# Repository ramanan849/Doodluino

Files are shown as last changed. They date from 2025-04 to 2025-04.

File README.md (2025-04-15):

# Doodluino: Doodle Jump on Arduino - PH222, Spring '25 Digital Electronics Project

Gokularamanan R S, 23B1854
-
[Project Report](https://github.com/ramanan849/Doodluino/blob/b796de5456497a73b1f6233cb64882a1899941b5/23B1854_Gokularamanan_Doodluino.pdf)
-
- This repo contains the entire version history of my project code, right version 1, till verion 7.4 (the demo day version), the final one. Some of the earlier ones might not be as refined as the latter ones, in terms of both documentation and stability. But, all of them use the same pins for the TFT display, but some versions might have different pins for the joystick. Also, the earlier versions (<= version 4 and or 5) might not have the speaker, LM386 amplifier and musical notes code in them. 
- The log file I tried to maintain : https://docs.google.com/spreadsheets/d/124PygBUTDnI5tR8Jvsb0EWS77CMUWYxi1bj8dvN-BO4/edit?usp=sharing
- [The CAD model files](https://github.com/ramanan849/Doodluino/blob/c0d4e8d1f5cbd4b15ecd3362300d9d8f78787e9c/consoluino%20v3.f3d)
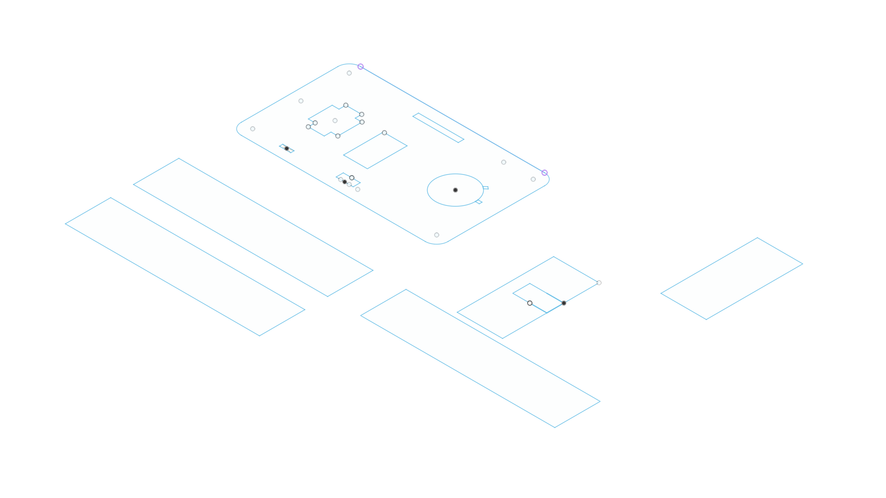
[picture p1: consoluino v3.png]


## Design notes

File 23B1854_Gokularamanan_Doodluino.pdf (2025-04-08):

PH222 | Final Report – 23B1854 | Page 1 of 32
Student: Gokularamanan R S | Roll Number: 23B1854

# Project Title: Doodluino: Doodle Jump on Arduino

# Project Abstract –

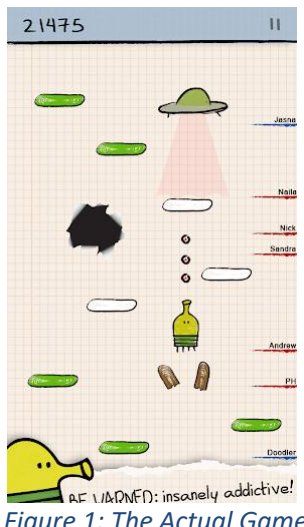
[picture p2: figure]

- Introduction – Doodle Jump is a classic arcade game where players control a small character (the "Doodler") that continuously jumps on randomly spawning, dynamic and stationary platforms, trying to ascend as high as possible without falling. Using a Joystick to move the Doodler left or right, we aim not to fall or get attacked by obstacles like enemies, moving platforms with spikes, and black holes that appear along the way. There are also power-ups, such as

springs and jetpacks that help us jump higher. Ultimately, the goal is to survive and to achieve the highest score.

# - The Grand Goal – TO obtain and simulate the complete version of the game on an Arduino UNO board, respecting all

the game physics and simulations involved.

- Collision detections - SPI update rate - Multi-object dynamics - Interrupts - for performing separate tasks simultaneously, or with minimum delay (in my case, simultaneously playing background music during gameplay through Arduino connected speaker) - EEPROM Memory Allocation - The main inputs and outputs – - Inputs: ■ Joystick – Left and Right Control, Top and Bottom, and Switch - Outputs: ■ TFT Display to display the game ■ Speaker to play game-play music - During the DEMO, I would like to demonstrate my game, by playing each of the Game Levels, showcasing the various features that have been built into it – like

EEPROM utilization, Interrupts, etc.

# - Role of the Arduino – It is the brain of the game. It gets joystick input, outputs the game mechanics to the TFT display and audio via the speaker, powered by the

### Figure 1: The Actual Game

### Credits: Lima Sky (game dev)

LM386 low-power amplifier.

# Project Detail –

# - The major components used –

# 1. Arduino UNO (32 kB storage and 2 kB RAM, with 1 KB allocated for EEPROM) 2. Adafruit ILI9341 2.8’’ TFT SPI Display

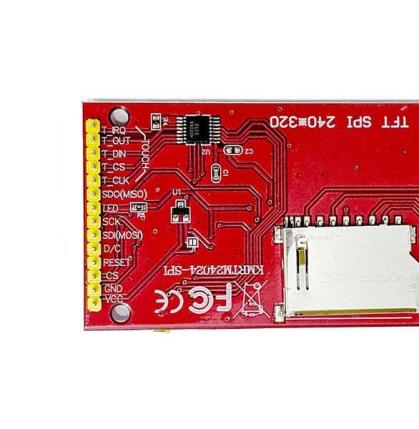
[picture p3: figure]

# 3. Analog Joystick (Left-Right, Top-Bottom, and Select button/ Switch) 4. Speaker (8 Ohm, 0.5 W) 5. LM386, Low Power Amplifier

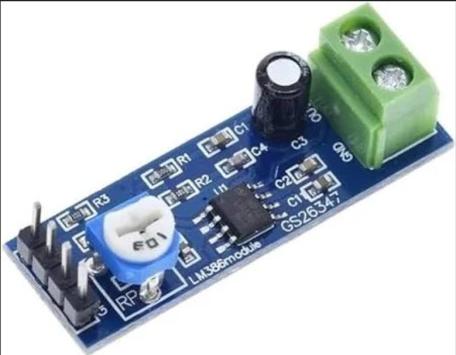
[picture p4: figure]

# 6. Potential Divider Circuit (Used 2.2 Ohm and 3.3 Ohm resistors to precisely deliver 3 V from Arduino 5 V to TFT display, to make sure that it doesn’t get damaged due to heavy load)

## Ref: https://cdn-shop.adafruit.com/datasheets/ILI9341.pdf

# The important pins:

# 1. CS (Chip Select) - Selects ILI9341 for communication 2. DC - Data/Command 3. RST - Reset 4. MOSI - Master Out Slave In 5. SCK – Serial Clock, operates at 16 MHz, same as Uno

# LM386 amplifier –

# 1. operates on a low voltage

2. adjustable gain control,

# using the potentiometer knob

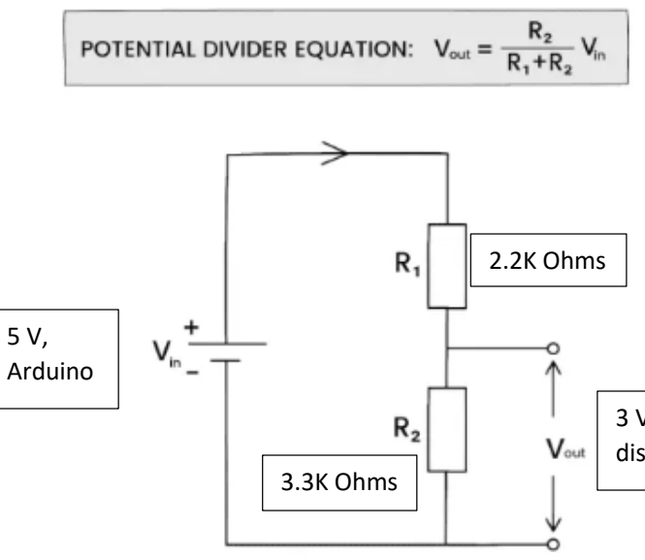
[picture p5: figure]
2.2K Ohms; 3.3K Ohms; Arduino

5 V,

### 3 V to each of the 5 display pins listed above

# - Hardware block diagram –

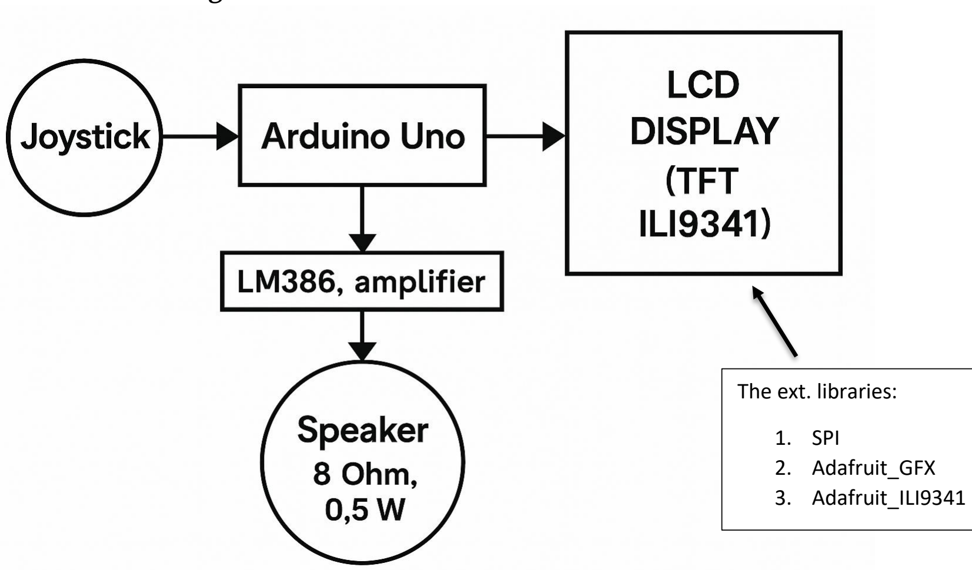
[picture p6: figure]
The ext. libraries:; 1. SPI 2. Adafruit_GFX 3. Adafruit_ILI9341

# - Final Circuit Diagram – (next page)

### Figure 2: Circuit Diagram - Arduino

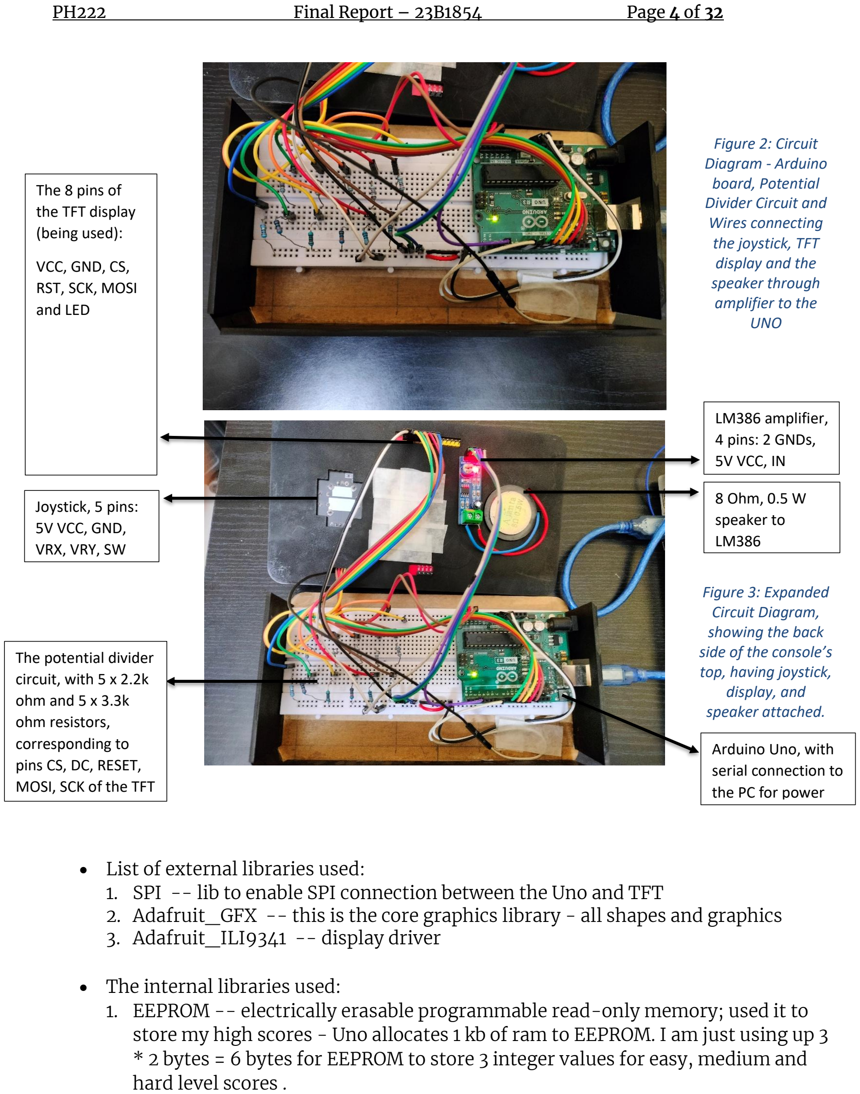
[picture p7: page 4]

# - List of external libraries used: 1. SPI -- lib to enable SPI connection between the Uno and TFT 2. Adafruit_GFX -- this is the core graphics library - all shapes and graphics 3. Adafruit_ILI9341 -- display driver

# - The internal libraries used: 1. EEPROM -- electrically erasable programmable read-only memory; used it to store my high scores - Uno allocates 1 kb of ram to EEPROM. I am just using up 3 * 2 bytes = 6 bytes for EEPROM to store 3 integer values for easy, medium and

hard level scores .

### board, Potential Divider Circuit and Wires connecting the joystick, TFT display and the speaker through amplifier to the UNO

### Figure 3: Expanded

Circuit Diagram,

### showing the back side of the console’s

top, having joystick,

### display, and

speaker attached.

### The 8 pins of the TFT display (being used):

VCC, GND, CS,

### RST, SCK, MOSI and LED

### Joystick, 5 pins:

5V VCC, GND,

### VRX, VRY, SW

### The potential divider circuit, with 5 x 2.2k ohm and 5 x 3.3k

ohm resistors,

### corresponding to

pins CS, DC, RESET,

### MOSI, SCK of the TFT

### Arduino Uno, with serial connection to the PC for power

LM386 amplifier,
4 pins: 2 GNDs,

### 5V VCC, IN

### 8 Ohm, 0.5 W speaker to

LM386

### Joystick

### TFT, displaying the game’s main menu

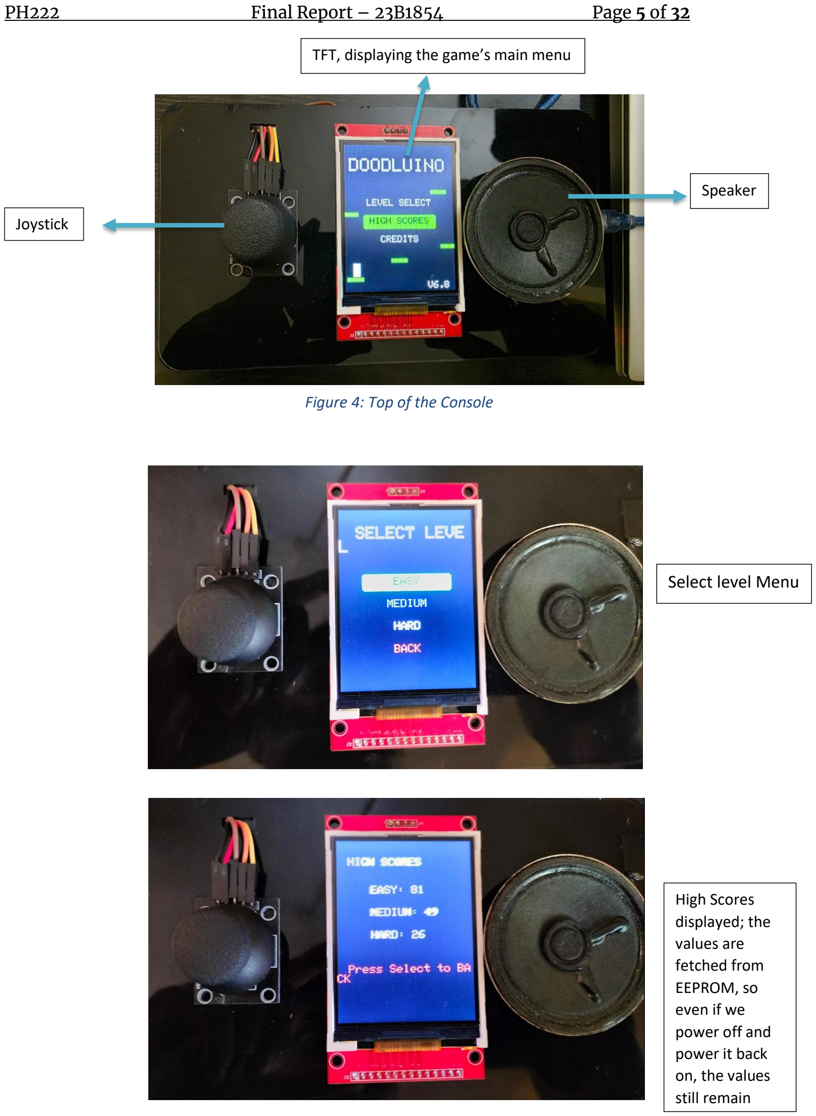
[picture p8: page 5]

### Speaker

### Figure 4: Top of the Console

## Select level Menu

### High Scores displayed; the values are fetched from EEPROM, so even if we power off and power it back on, the values still remain

# - Video Demonstration –

# 1. With Gameplay music

## https://www.youtube.com/watch?v=0u_XmoVJk0Y

# 2. Without gameplay music

## https://www.youtube.com/watch?v=of0zH08SPe8

# Milestones achieved in each week –

1. Note: Since my game involved a lot of components - functions, structures, etc.,

# each of which formed an integral part of my code, I maintained a separate log sheet of my updates every week, what I intended to complete, and the glitches and problems that I faced and needed to rectify along the way:

## https://docs.google.com/spreadsheets/d/124PygBUTDnI5tR8Jvsb0EWS77CMUWYxi1bj8dv

N-BO4/edit?usp=sharing (https://docs.google.com/spreadsheets/d/124PygBUTDnI5tR8Jvsb0EWS77CMUWYxi1bj8dvN-BO4/edit?usp=sharing)

# This turned out to be very useful at the end - I could just check whether I had fixed something or not, since it was very easy to forget very minor, yet hard to fix

glitches.

# 2. Note: I also created a GitHub Repository where I have posted all versions of my

## code, ranging from Version 1.00 to 7.xx: https://github.com/ramanan849/Doodluino

# 3. Overview of my progress throughout the project phase, weekly:

# WEEK 1 – A. Formulated a plan of how I am going to build my project – a basic version of

what kind of features I wanted to build, how I am going to get going with it.

# B. Familiarized myself with the various Arduino components that would be

required.

# C. Explored various Arduino libraries that were capable of displaying animated

objects on a TFT display. Chose to use the TFT library provided by Adafruit. Also, went through others, such as the “TFT-eSPI library” (sadly, incompatible with the UNO due to low clock frequency).

# D. Then, wrote a simple program to animate bouncing balls (my video link:

## https://youtu.be/ppXeX2nozWA)

# WEEK 2 –

# A. Implementing the moving platforms, warp left and right mechanisms, the skeletal features of the game, while optimizing game dynamics to improve animation and FPS

# WEEK 3 –

# A. Designing the in-game graphics - characters and obstacles B. Adding logic to store previous data – EEPROM , such as high scores, and obtaining velocity and position data

# WEEK 4 –

# A. Worked on game GUI B. Tried fixing the SD card and SPI issues

# WEEK 5 –

# A. Fixed Glitches in the game – for Level Easy, Medium and Hard

# B. Worked on using interrupts to play music and play the game simultaneously

# WEEK 6 –

# A. Fixed glitches B. Worked on creating a console from acrylic, used CAD to design the model C. Report

# Code – (As of Tuesday, 08/04/2025, Subject To Change By Demo Day)

// v7.0 - Doodle Jump - As of 08/04/2025
// Gokularamanan RS
// https://github.com/ramanan849/doodluino

/*
List of all the functions in the code, with a one-line explanation :
1. initializeEEPROM()-
2. setup()
3. loop()
4. resetDrawFlags()
5. drawMainMenu()
6. drawLevelMenu()
7. drawHighScores()
8. drawCredits()
9. readMenuInput()
10. handleMenuSelection()
11. readMenuInput_GameOver()
12. updatePlatforms()
13. updateObstacles()
14. drawGame()
15. checkCollisions()
16. initGame()
17. updateMusic()
18. handleGameOver()
19. checkGameOver()
20. handleScrolling()
*/

#include <SPI.h> // lib to enable SPI connection between the Uno and TFT #include <Adafruit_GFX.h> // this is the core graphics library - all shapes and graphics

#include <Adafruit_ILI9341.h> // display driver

#include <EEPROM.h> // EEPROM - electrically erasable programmable read-only memory //- to store my high scores - Uno, i belive allocates 1 kb of ram to eeprom. I am just using up 3 * 2 bytes = 6 bytes for eeprom to store 3 integer values for easy, medium and hard level scores

// --- Pin Definitions ---
// i am using 8 pins on my tft - cs, dc, rst, sck (serial clock), mosi (master out slave in)
#define TFT_CS 10

#define TFT_DC 9

#define TFT_RST 8

#define JOY_X A5

#define JOY_Y A3

#define JOY_SW 6

#define BUZZER_PIN 2

// --- Game Constants ---
#define SCREEN_WIDTH 240

#define SCREEN_HEIGHT 320

// the display is a 240x320 unit #define DOODLER_WIDTH 15
#define DOODLER_HEIGHT 28

#define PLATFORM_WIDTH 40

#define PLATFORM_HEIGHT 8

#define NUM_PLATFORMS 7

#define MAX_SCROLL 5 // Smoother scrolling

#define JUMP_FORCE -12

#define GRAVITY 0.4 // dynamic gravity in updateGame

#define TOP_OFFSET 30 // Height of score panel - the separate one # define BOTTOM_OFFSET 40

#define PLAY_AREA_HEIGHT (SCREEN_HEIGHT - TOP_OFFSET)

#define VISIBLE_PLATFORMS 7 // Start with 7 platforms

#define BASE_SCROLL 5 | // Base scroll speed

#define SCROLL_INCREASE 0.1 // Scroll speed increase per score #define BASE_GRAVITY 0.4 // Base gravity

#define GRAVITY_INCREASE 0.01 // Gravity increase per score #define OBSTACLE_SPEED 2

// <<< NEW: Obstacle Constants >>> #define MAX_OBSTACLES 2
#define OBSTACLE_RADIUS 8

#define OBSTACLE_COLOR RED

#define OBSTACLE_START_SCORE 5

#define OBSTACLE_SPAWN_CHANCE 3 // 3% chance per frame #define OBSTACLE_SPEED 2

#define MIN_OBSTACLE_DISTANCE 40

// --- Game States ---
#define MAIN_MENU 0

#define LEVEL_MENU 1

#define HIGHSCORES_MENU 2

#define CREDITS_MENU 3

#define GAME_PLAYING 4

#define GAME_OVER_STATE 5

// --- Color Definitions ---#define BLACK 0x0000
#define WHITE 0xFFFF

#define GREEN 0x07E0

#define BLUE 0x001F

#define RED 0xF800

#define YELLOW 0xFFE0

#define MAGENTA 0xF81F

#define CYAN 0x07FF

#define LEVEL_EASY 0

#define LEVEL_MEDIUM 1

#define LEVEL_HARD 2

// Musical note definitions
#define NOTE_B0 | 31

#define NOTE_C1 | 33

#define NOTE_CS1 35

#define NOTE_D1 37

#define NOTE_DS1 39

#define NOTE_E1 | 41

#define NOTE_F1 | 44

#define NOTE_FS1 46

#define NOTE_G1 49

#define NOTE_GS1 52

#define NOTE_A1 55

#define NOTE_AS1 58

#define NOTE_B1 62

PH222 | Final Report
– 23B1854 | Page 11 of 32
#define NOTE_C2 | 65

#define NOTE_CS2 69

#define NOTE_D2 73

#define NOTE_DS2 78

#define NOTE_E2 | 82

#define NOTE_F2 | 87

#define NOTE_FS2 93

#define NOTE_G2 98

#define NOTE_GS2 104

#define NOTE_A2 110

#define NOTE_AS2 117

#define NOTE_B2 | 123

#define NOTE_C3 | 131

#define NOTE_CS3 139

#define NOTE_D3 147

#define NOTE_DS3 156

#define NOTE_E3 | 165

#define NOTE_F3 | 175

#define NOTE_FS3 185

#define NOTE_G3 196

#define NOTE_GS3 208

#define NOTE_A3 220

#define NOTE_AS3 233

#define NOTE_B3 | 247

#define NOTE_C4 | 262

#define NOTE_CS4 277

#define NOTE_D4 294

#define NOTE_DS4 311

#define NOTE_E4 | 330

#define NOTE_F4 | 349

#define NOTE_FS4 370

#define NOTE_G4 392

#define NOTE_GS4 415

#define NOTE_A4 440

#define NOTE_AS4 466

#define NOTE_B4 | 494

#define NOTE_C5 | 523

#define NOTE_CS5 554

#define NOTE_D5 587

#define NOTE_DS5 622

#define NOTE_E5 | 659

#define NOTE_F5 | 698

#define NOTE_FS5 740

#define NOTE_G5 784

#define NOTE_GS5 831

#define NOTE_A5 880

#define NOTE_AS5 932

#define NOTE_B5 | 988

#define NOTE_C6 | 1047

#define NOTE_CS6 1109

#define NOTE_D6 1175

#define NOTE_DS6 1245

#define NOTE_E6 | 1319

#define NOTE_F6 | 1397

#define NOTE_FS6 1480

#define NOTE_G6 1568

#define NOTE_GS6 1661

#define NOTE_A6 1760

#define NOTE_AS6 1865

#define NOTE_B6 | 1976

#define NOTE_C7 | 2093

#define NOTE_CS7 2217

#define NOTE_D7 2349

#define NOTE_DS7 2489

#define NOTE_E7 | 2637

#define NOTE_F7 | 2794

#define NOTE_FS7 2960

#define NOTE_G7 3136

#define NOTE_GS7 3322

#define NOTE_A7 3520

#define NOTE_AS7 3729

#define NOTE_B7 | 3951

#define NOTE_C8 | 4186

#define NOTE_CS8 4435

#define NOTE_D8 4699

#define NOTE_DS8 4978

#define REST | 0

enum MusicState { MUSIC_OFF, MUSIC_MAIN, MUSIC_GAME_OVER, MUSIC_CREDITS, MUSIC_HARD }; // basically like a list/ set to store music realted constants

struct GameState { // the most important part of my game - this structure contains most of the variables for spawning platforms, obstacles, making animation and player - arduino interactions possible
int doodlerX, doodlerY;
float doodlerVelocityY;
int platformX[NUM_PLATFORMS];
int platformY[NUM_PLATFORMS];
int platformDirection[NUM_PLATFORMS]; int score = 0;
bool gameOver = true;
bool platformUsed[NUM_PLATFORMS]; int prevDoodlerX, prevDoodlerY; int prevPlatformX[NUM_PLATFORMS];
int prevPlatformY[NUM_PLATFORMS];
int gameLevel = 0;
int selectedOption = 0; // Used by original readMenuInput, now new menu too bool levelSelected = false;
int platformX_start;
int platformY_start;
bool plat_start_used;
bool gameStartedByUser;
int visiblePlatforms;
float displayGravity;
// <<< NEW: Menu state variables >>>
int currentMenu; // Current state (menu, game, etc.) int mainMenuSelection = 0; // For main menu navigation bool gameIsActive = false; // v6.3
// <<< NEW: Obstacle variables >>>
int obstacleX[MAX_OBSTACLES];
int obstacleY[MAX_OBSTACLES];
int obstacleDir[MAX_OBSTACLES]; // 1 = right, -1 = left bool obstacleActive[MAX_OBSTACLES];
int prevObstacleX[MAX_OBSTACLES];
int prevObstacleY[MAX_OBSTACLES];
// the variables corresponding to music MusicState musicState;
int currentMelodyNote;
unsigned long previousNoteTime;
int melodyNoteDuration;
const int* currentMelody;
int currentTempo;
int currentNotesCount;

};

const int melody[] PROGMEM = {
// I took the code from https://github.com/robsoncouto/arduino-songs -- TRUE GOAT // Super Mario Bros theme
// Score available at https://musescore.com/user/2123/scores/2145
// Theme by Koji Kondo
NOTE_E5,8, NOTE_E5,8, REST,8, NOTE_E5,8, REST,8, NOTE_C5,8, NOTE_E5,8, //1 NOTE_G5,4, REST,4, NOTE_G4,8, REST,4,
NOTE_C5,-4, NOTE_G4,8, REST,4, NOTE_E4,-4, // 3
NOTE_A4,4, NOTE_B4,4, NOTE_AS4,8, NOTE_A4,4,
NOTE_G4,-8, NOTE_E5,-8, NOTE_G5,-8, NOTE_A5,4, NOTE_F5,8, NOTE_G5,8, REST,8, NOTE_E5,4,NOTE_C5,8, NOTE_D5,8, NOTE_B4,-4,
NOTE_C5,-4, NOTE_G4,8, REST,4, NOTE_E4,-4, // repeats from 3 NOTE_A4,4, NOTE_B4,4, NOTE_AS4,8, NOTE_A4,4,
NOTE_G4,-8, NOTE_E5,-8, NOTE_G5,-8, NOTE_A5,4, NOTE_F5,8, NOTE_G5,8, REST,8, NOTE_E5,4,NOTE_C5,8, NOTE_D5,8, NOTE_B4,-4,

REST,4, NOTE_G5,8, NOTE_FS5,8, NOTE_F5,8, NOTE_DS5,4, NOTE_E5,8,//7 REST,8, NOTE_GS4,8, NOTE_A4,8, NOTE_C4,8, REST,8, NOTE_A4,8, NOTE_C5,8, NOTE_D5,8,
REST,4, NOTE_DS5,4, REST,8, NOTE_D5,-4,
NOTE_C5,2, REST,2,

REST,4, NOTE_G5,8, NOTE_FS5,8, NOTE_F5,8, NOTE_DS5,4, NOTE_E5,8,//repeats from 7 REST,8, NOTE_GS4,8, NOTE_A4,8, NOTE_C4,8, REST,8, NOTE_A4,8, NOTE_C5,8, NOTE_D5,8,
REST,4, NOTE_DS5,4, REST,8, NOTE_D5,-4,
NOTE_C5,2, REST,2,

NOTE_C5,8, NOTE_C5,4, NOTE_C5,8, REST,8, NOTE_C5,8, NOTE_D5,4,//11 NOTE_E5,8, NOTE_C5,4, NOTE_A4,8, NOTE_G4,2,

NOTE_C5,8, NOTE_C5,4, NOTE_C5,8, REST,8, NOTE_C5,8, NOTE_D5,8, NOTE_E5,8,//13 REST,1,
NOTE_C5,8, NOTE_C5,4, NOTE_C5,8, REST,8, NOTE_C5,8, NOTE_D5,4,
NOTE_E5,8, NOTE_C5,4, NOTE_A4,8, NOTE_G4,2,
NOTE_E5,8, NOTE_E5,8, REST,8, NOTE_E5,8, REST,8, NOTE_C5,8, NOTE_E5,4, NOTE_G5,4, REST,4, NOTE_G4,4, REST,4,
NOTE_C5,-4, NOTE_G4,8, REST,4, NOTE_E4,-4, // 19

NOTE_A4,4, NOTE_B4,4, NOTE_AS4,8, NOTE_A4,4,
NOTE_G4,-8, NOTE_E5,-8, NOTE_G5,-8, NOTE_A5,4, NOTE_F5,8, NOTE_G5,8, REST,8, NOTE_E5,4, NOTE_C5,8, NOTE_D5,8, NOTE_B4,-4,

NOTE_C5,-4, NOTE_G4,8, REST,4, NOTE_E4,-4, // repeats from 19 NOTE_A4,4, NOTE_B4,4, NOTE_AS4,8, NOTE_A4,4,
NOTE_G4,-8, NOTE_E5,-8, NOTE_G5,-8, NOTE_A5,4, NOTE_F5,8, NOTE_G5,8, REST,8, NOTE_E5,4, NOTE_C5,8, NOTE_D5,8, NOTE_B4,-4,

NOTE_E5,8, NOTE_C5,4, NOTE_G4,8, REST,4, NOTE_GS4,4,//23
NOTE_A4,8, NOTE_F5,4, NOTE_F5,8, NOTE_A4,2,
NOTE_D5,-8, NOTE_A5,-8, NOTE_A5,-8, NOTE_A5,-8, NOTE_G5,-8, NOTE_F5,-8,

NOTE_E5,8, NOTE_C5,4, NOTE_A4,8, NOTE_G4,2, //26
NOTE_E5,8, NOTE_C5,4, NOTE_G4,8, REST,4, NOTE_GS4,4,
NOTE_A4,8, NOTE_F5,4, NOTE_F5,8, NOTE_A4,2,
NOTE_B4,8, NOTE_F5,4, NOTE_F5,8, NOTE_F5,-8, NOTE_E5,-8, NOTE_D5,-8, NOTE_C5,8, NOTE_E4,4, NOTE_E4,8, NOTE_C4,2,

NOTE_E5,8, NOTE_C5,4, NOTE_G4,8, REST,4, NOTE_GS4,4,//repeats from 23

NOTE_A4,8, NOTE_F5,4, NOTE_F5,8, NOTE_A4,2,
NOTE_D5,-8, NOTE_A5,-8, NOTE_A5,-8, NOTE_A5,-8, NOTE_G5,-8, NOTE_F5,-8,

NOTE_E5,8, NOTE_C5,4, NOTE_A4,8, NOTE_G4,2, //26
NOTE_E5,8, NOTE_C5,4, NOTE_G4,8, REST,4, NOTE_GS4,4,
NOTE_A4,8, NOTE_F5,4, NOTE_F5,8, NOTE_A4,2,
NOTE_B4,8, NOTE_F5,4, NOTE_F5,8, NOTE_F5,-8, NOTE_E5,-8, NOTE_D5,-8, NOTE_C5,8, NOTE_E4,4, NOTE_E4,8, NOTE_C4,2,
NOTE_C5,8, NOTE_C5,4, NOTE_C5,8, REST,8, NOTE_C5,8, NOTE_D5,8, NOTE_E5,8, REST,1,

NOTE_C5,8, NOTE_C5,4, NOTE_C5,8, REST,8, NOTE_C5,8, NOTE_D5,4, //33 NOTE_E5,8, NOTE_C5,4, NOTE_A4,8, NOTE_G4,2,
NOTE_E5,8, NOTE_E5,8, REST,8, NOTE_E5,8, REST,8, NOTE_C5,8, NOTE_E5,4, NOTE_G5,4, REST,4, NOTE_G4,4, REST,4,
NOTE_E5,8, NOTE_C5,4, NOTE_G4,8, REST,4, NOTE_GS4,4,
NOTE_A4,8, NOTE_F5,4, NOTE_F5,8, NOTE_A4,2,
NOTE_D5,-8, NOTE_A5,-8, NOTE_A5,-8, NOTE_A5,-8, NOTE_G5,-8, NOTE_F5,-8,

NOTE_E5,8, NOTE_C5,4, NOTE_A4,8, NOTE_G4,2, //40
NOTE_E5,8, NOTE_C5,4, NOTE_G4,8, REST,4, NOTE_GS4,4,
NOTE_A4,8, NOTE_F5,4, NOTE_F5,8, NOTE_A4,2,
NOTE_B4,8, NOTE_F5,4, NOTE_F5,8, NOTE_F5,-8, NOTE_E5,-8, NOTE_D5,-8, NOTE_C5,8, NOTE_E4,4, NOTE_E4,8, NOTE_C4,2,
};

const int gameOver[] PROGMEM = {
// Super Mario's gameOver
// I took the code from https://github.com/robsoncouto/arduino-songs -- TRUE GOAT NOTE_C5,-4, NOTE_G4,-4, NOTE_E4,4, //45
NOTE_A4,-8, NOTE_B4,-8, NOTE_A4,-8, NOTE_GS4,-8, NOTE_AS4,-8, NOTE_GS4,-8, NOTE_G4,8, NOTE_D4,8, NOTE_E4,-2,
};

const int hardMelody[] PROGMEM = {
// credits: Beethoven
// I took the code from https://github.com/robsoncouto/arduino-songs -- TRUE GOAT NOTE_E5, 16, NOTE_DS5, 16, //1
NOTE_E5, 16, NOTE_DS5, 16, NOTE_E5, 16, NOTE_B4, 16, NOTE_D5, 16, NOTE_C5, 16, NOTE_A4, -8, NOTE_C4, 16, NOTE_E4, 16, NOTE_A4, 16,
NOTE_B4, -8, NOTE_E4, 16, NOTE_GS4, 16, NOTE_B4, 16,
NOTE_C5, 8, | REST, 16, NOTE_E4, 16, NOTE_E5, 16, | NOTE_DS5, 16,

NOTE_E5, 16, NOTE_DS5, 16, NOTE_E5, 16, NOTE_B4, 16, NOTE_D5, 16, NOTE_C5, 16,//6 NOTE_A4, -8, NOTE_C4, 16, NOTE_E4, 16, NOTE_A4, 16,
NOTE_B4, -8, NOTE_E4, 16, NOTE_C5, 16, NOTE_B4, 16,
NOTE_A4 , 4, REST, 8, //9 - 1st ending

//repaets from 1 ending on 10
NOTE_E5, 16, NOTE_DS5, 16, //1
NOTE_E5, 16, NOTE_DS5, 16, NOTE_E5, 16, NOTE_B4, 16, NOTE_D5, 16, NOTE_C5, 16, NOTE_A4, -8, NOTE_C4, 16, NOTE_E4, 16, NOTE_A4, 16,
NOTE_B4, -8, NOTE_E4, 16, NOTE_GS4, 16, NOTE_B4, 16,
NOTE_C5, 8, | REST, 16, NOTE_E4, 16, NOTE_E5, 16, | NOTE_DS5, 16,

NOTE_E5, 16, NOTE_DS5, 16, NOTE_E5, 16, NOTE_B4, 16, NOTE_D5, 16, NOTE_C5, 16,//6 NOTE_A4, -8, NOTE_C4, 16, NOTE_E4, 16, NOTE_A4, 16,
NOTE_B4, -8, NOTE_E4, 16, NOTE_C5, 16, NOTE_B4, 16,
NOTE_A4, 8, REST, 16, NOTE_B4, 16, NOTE_C5, 16, NOTE_D5, 16, //10 - 2nd ending //continues from 11
NOTE_E5, -8, NOTE_G4, 16, NOTE_F5, 16, NOTE_E5, 16,
NOTE_D5, -8, NOTE_F4, 16, NOTE_E5, 16, NOTE_D5, 16, //12

NOTE_C5, -8, NOTE_E4, 16, NOTE_D5, 16, NOTE_C5, 16, //13
NOTE_B4, 8, REST, 16, NOTE_E4, 16, NOTE_E5, 16, REST, 16,
REST, 16, NOTE_E5, 16, NOTE_E6, 16, REST, 16, REST, 16, NOTE_DS5, 16, NOTE_E5, 16, REST, 16, REST, 16, NOTE_DS5, 16, NOTE_E5, 16, NOTE_DS5, 16, NOTE_E5, 16, NOTE_DS5, 16, NOTE_E5, 16, NOTE_B4, 16, NOTE_D5, 16, NOTE_C5, 16, NOTE_A4, 8, REST, 16, NOTE_C4, 16, NOTE_E4, 16, NOTE_A4, 16,

NOTE_B4, 8, REST, 16, NOTE_E4, 16, NOTE_GS4, 16, NOTE_B4, 16, //19
NOTE_C5, 8, REST, 16, NOTE_E4, 16, NOTE_E5, 16, NOTE_DS5, 16,
NOTE_E5, 16, NOTE_DS5, 16, NOTE_E5, 16, NOTE_B4, 16, NOTE_D5, 16, NOTE_C5, 16, NOTE_A4, 8, REST, 16, NOTE_C4, 16, NOTE_E4, 16, NOTE_A4, 16,
NOTE_B4, 8, REST, 16, NOTE_E4, 16, NOTE_C5, 16, NOTE_B4, 16,
NOTE_A4, 8, REST, 16, NOTE_B4, 16, NOTE_C5, 16, NOTE_D5, 16, //24 (1st ending)

//repeats from 11
NOTE_E5, -8, NOTE_G4, 16, NOTE_F5, 16, NOTE_E5, 16,
NOTE_D5, -8, NOTE_F4, 16, NOTE_E5, 16, NOTE_D5, 16, //12

NOTE_C5, -8, NOTE_E4, 16, NOTE_D5, 16, NOTE_C5, 16, //13
NOTE_B4, 8, REST, 16, NOTE_E4, 16, NOTE_E5, 16, REST, 16,
REST, 16, NOTE_E5, 16, NOTE_E6, 16, REST, 16, REST, 16, NOTE_DS5, 16, NOTE_E5, 16, REST, 16, REST, 16, NOTE_DS5, 16, NOTE_E5, 16, NOTE_DS5, 16, NOTE_E5, 16, NOTE_DS5, 16, NOTE_E5, 16, NOTE_B4, 16, NOTE_D5, 16, NOTE_C5, 16, NOTE_A4, 8, REST, 16, NOTE_C4, 16, NOTE_E4, 16, NOTE_A4, 16,

NOTE_B4, 8, REST, 16, NOTE_E4, 16, NOTE_GS4, 16, NOTE_B4, 16, //19
NOTE_C5, 8, REST, 16, NOTE_E4, 16, NOTE_E5, 16, NOTE_DS5, 16,
NOTE_E5, 16, NOTE_DS5, 16, NOTE_E5, 16, NOTE_B4, 16, NOTE_D5, 16, NOTE_C5, 16, NOTE_A4, 8, REST, 16, NOTE_C4, 16, NOTE_E4, 16, NOTE_A4, 16,
NOTE_B4, 8, REST, 16, NOTE_E4, 16, NOTE_C5, 16, NOTE_B4, 16,
NOTE_A4, 8, REST, 16, NOTE_C5, 16, NOTE_C5, 16, NOTE_C5, 16, //25 - 2nd ending

//continues from 26
NOTE_C5 , 4, NOTE_F5, -16, NOTE_E5, 32, //26
NOTE_E5, 8, NOTE_D5, 8, NOTE_AS5, -16, NOTE_A5, 32,
NOTE_A5, 16, NOTE_G5, 16, NOTE_F5, 16, NOTE_E5, 16, NOTE_D5, 16, NOTE_C5, 16, NOTE_AS4, 8, NOTE_A4, 8, NOTE_A4, 32, NOTE_G4, 32, NOTE_A4, 32, NOTE_B4, 32, NOTE_C5 , 4, NOTE_D5, 16, NOTE_DS5, 16,
NOTE_E5, -8, NOTE_E5, 16, NOTE_F5, 16, NOTE_A4, 16,
NOTE_C5 , 4, NOTE_D5, -16, NOTE_B4, 32,

NOTE_C5, 32, NOTE_G5, 32, NOTE_G4, 32, NOTE_G5, 32, NOTE_A4, 32, NOTE_G5, 32, NOTE_B4, 32, NOTE_G5, 32, NOTE_C5, 32, NOTE_G5, 32, NOTE_D5, 32, NOTE_G5, 32, //33 NOTE_E5, 32, NOTE_G5, 32, NOTE_C6, 32, NOTE_B5, 32, NOTE_A5, 32, NOTE_G5, 32, NOTE_F5, 32, NOTE_E5, 32, NOTE_D5, 32, NOTE_G5, 32, NOTE_F5, 32, NOTE_D5, 32, NOTE_C5, 32, NOTE_G5, 32, NOTE_G4, 32, NOTE_G5, 32, NOTE_A4, 32, NOTE_G5, 32, NOTE_B4, 32, NOTE_G5, 32, NOTE_C5, 32, NOTE_G5, 32, NOTE_D5, 32, NOTE_G5, 32,

NOTE_E5, 32, NOTE_G5, 32, NOTE_C6, 32, NOTE_B5, 32, NOTE_A5, 32, NOTE_G5, 32, NOTE_F5, 32, NOTE_E5, 32, NOTE_D5, 32, NOTE_G5, 32, NOTE_F5, 32, NOTE_D5, 32, //36 NOTE_E5, 32, NOTE_F5, 32, NOTE_E5, 32, NOTE_DS5, 32, NOTE_E5, 32, NOTE_B4, 32, NOTE_E5, 32, NOTE_DS5, 32, NOTE_E5, 32, NOTE_B4, 32, NOTE_E5, 32, NOTE_DS5, 32, NOTE_E5, -8, NOTE_B4, 16, NOTE_E5, 16, NOTE_DS5, 16,
NOTE_E5, -8, NOTE_B4, 16, NOTE_E5, 16, REST, 16,

REST, 16, NOTE_DS5, 16, NOTE_E5, 16, REST, 16, REST, 16, NOTE_DS5, 16, //40 NOTE_E5, 16, NOTE_DS5, 16, NOTE_E5, 16, NOTE_B4, 16, NOTE_D5, 16, NOTE_C5, 16, NOTE_A4, 8, REST, 16, NOTE_C4, 16, NOTE_E4, 16, NOTE_A4, 16,
NOTE_B4, 8, REST, 16, NOTE_E4, 16, NOTE_GS4, 16, NOTE_B4, 16,
NOTE_C5, 8, REST, 16, NOTE_E4, 16, NOTE_E5, 16, NOTE_DS5, 16,

NOTE_E5, 16, NOTE_DS5, 16, NOTE_E5, 16, NOTE_B4, 16, NOTE_D5, 16, NOTE_C5, 16,

NOTE_A4, 8, REST, 16, NOTE_C4, 16, NOTE_E4, 16, NOTE_A4, 16, //46
NOTE_B4, 8, REST, 16, NOTE_E4, 16, NOTE_C5, 16, NOTE_B4, 16,
NOTE_A4, 8, REST, 16, NOTE_B4, 16, NOTE_C5, 16, NOTE_D5, 16, NOTE_E5, -8, NOTE_G4, 16, NOTE_F5, 16, NOTE_E5, 16,
NOTE_D5, -8, NOTE_F4, 16, NOTE_E5, 16, NOTE_D5, 16,
NOTE_C5, -8, NOTE_E4, 16, NOTE_D5, 16, NOTE_C5, 16,
NOTE_B4, 8, REST, 16, NOTE_E4, 16, NOTE_E5, 16, REST, 16,
REST, 16, NOTE_E5, 16, NOTE_E6, 16, REST, 16, REST, 16, NOTE_DS5, 16,

NOTE_E5, 16, REST, 16, REST, 16, NOTE_DS5, 16, NOTE_E5, 16, NOTE_D5, 16, //54 NOTE_E5, 16, NOTE_DS5, 16, NOTE_E5, 16, NOTE_B4, 16, NOTE_D5, 16, NOTE_C5, 16, NOTE_A4, 8, REST, 16, NOTE_C4, 16, NOTE_E4, 16, NOTE_A4, 16,
NOTE_B4, 8, REST, 16, NOTE_E4, 16, NOTE_GS4, 16, NOTE_B4, 16,
NOTE_C5, 8, REST, 16, NOTE_E4, 16, NOTE_E5, 16, NOTE_DS5, 16,
NOTE_E5, 16, NOTE_DS5, 16, NOTE_E5, 16, NOTE_B4, 16, NOTE_D5, 16, NOTE_C5, 16,

NOTE_A4, 8, REST, 16, NOTE_C4, 16, NOTE_E4, 16, NOTE_A4, 16, //60
NOTE_B4, 8, REST, 16, NOTE_E4, 16, NOTE_C5, 16, NOTE_B4, 16,
NOTE_A4, 8, REST, 16, REST, 16, REST, 8,
NOTE_CS5 , -4,
NOTE_D5 , 4, NOTE_E5, 16, NOTE_F5, 16,
NOTE_F5 , 4, NOTE_F5, 8,
NOTE_E5 , -4,
NOTE_D5 , 4, NOTE_C5, 16, NOTE_B4, 16, NOTE_A4 , 4, NOTE_A4, 8,
NOTE_A4, 8, NOTE_C5, 8, NOTE_B4, 8, NOTE_A4 , -4,
NOTE_CS5 , -4,

NOTE_D5 , 4, NOTE_E5, 16, NOTE_F5, 16, //72 NOTE_F5 , 4, NOTE_F5, 8,
NOTE_F5 , -4,
NOTE_DS5 , 4, NOTE_D5, 16, NOTE_C5, 16, NOTE_AS4 , 4, NOTE_A4, 8,
NOTE_GS4 , 4, NOTE_G4, 8,
NOTE_A4 , -4,
NOTE_B4 , 4, REST, 8,
NOTE_A3, -32, NOTE_C4, -32, NOTE_E4, -32, NOTE_A4, -32, NOTE_C5, -32, NOTE_E5, -32, NOTE_D5, -32, NOTE_C5, -32, NOTE_B4, -32,

NOTE_A4, -32, NOTE_C5, -32, NOTE_E5, -32, NOTE_A5, -32, NOTE_C6, -32, NOTE_E6, -32, NOTE_D6, -32, NOTE_C6, -32, NOTE_B5, -32, //80
NOTE_A4, -32, NOTE_C5, -32, NOTE_E5, -32, NOTE_A5, -32, NOTE_C6, -32, NOTE_E6, -32, NOTE_D6, -32, NOTE_C6, -32, NOTE_B5, -32,
NOTE_AS5, -32, NOTE_A5, -32, NOTE_GS5, -32, NOTE_G5, -32, NOTE_FS5, -32, NOTE_F5, -32, NOTE_E5, -32, NOTE_DS5, -32, NOTE_D5, -32,

NOTE_CS5, -32, NOTE_C5, -32, NOTE_B4, -32, NOTE_AS4, -32, NOTE_A4, -32, NOTE_GS4, -32, NOTE_G4, -32, NOTE_FS4, -32, NOTE_F4, -32, //84
NOTE_E4, 16, NOTE_DS5, 16, NOTE_E5, 16, NOTE_B4, 16, NOTE_D5, 16, NOTE_C5, 16, NOTE_A4, -8, NOTE_C4, 16, NOTE_E4, 16, NOTE_A4, 16,
NOTE_B4, -8, NOTE_E4, 16, NOTE_GS4, 16, NOTE_B4, 16,

NOTE_C5, 8, REST, 16, NOTE_E4, 16, NOTE_E5, 16, NOTE_DS5, 16, //88
NOTE_E5, 16, NOTE_DS5, 16, NOTE_E5, 16, NOTE_B4, 16, NOTE_D5, 16, NOTE_C5, 16, NOTE_A4, -8, NOTE_C4, 16, NOTE_E4, 16, NOTE_A4, 16,
NOTE_B4, -8, NOTE_E4, 16, NOTE_C5, 16, NOTE_B4, 16,
NOTE_A4, -8, REST, -8,
REST, -8, NOTE_G4, 16, NOTE_F5, 16, NOTE_E5, 16, NOTE_D5 , 4, REST, 8,

REST, -8, NOTE_E4, 16, NOTE_D5, 16, NOTE_C5, 16,

NOTE_B4, -8, NOTE_E4, 16, NOTE_E5, 8, //96
NOTE_E5, 8, NOTE_E6, -8, NOTE_DS5, 16,
NOTE_E5, 16, REST, 16, REST, 16, NOTE_DS5, 16, NOTE_E5, 16, NOTE_DS5, 16, NOTE_E5, 16, NOTE_DS5, 16, NOTE_E5, 16, NOTE_B4, 16, NOTE_D5, 16, NOTE_C5, 16, NOTE_A4, -8, NOTE_C4, 16, NOTE_E4, 16, NOTE_A4, 16,
NOTE_B4, -8, NOTE_E4, 16, NOTE_GS4, 16, NOTE_B4, 16,

NOTE_C5, 8, REST, 16, NOTE_E4, 16, NOTE_E5, 16, NOTE_DS5, 16, //102
NOTE_E5, 16, NOTE_DS5, 16, NOTE_E5, 16, NOTE_B4, 16, NOTE_D5, 16, NOTE_C5, 16, NOTE_A4, -8, NOTE_C4, 16, NOTE_E4, 16, NOTE_A4, 16,
NOTE_B4, -8, NOTE_E4, 16, NOTE_C5, 16, NOTE_B4, 16,
NOTE_A4 , -4,
};

const int creditMelody[] PROGMEM = {
// credits : Never Gonna Give You Up, Rick AStley
// I took the code from https://github.com/robsoncouto/arduino-songs -- TRUE GOAT REST,8, NOTE_B4,8, NOTE_B4,8, NOTE_CS5,8, NOTE_D5,8, NOTE_B4,4, NOTE_A4,8, //7 NOTE_A5,8, REST,8, NOTE_A5,8, NOTE_E5,-4, REST,4,
NOTE_B4,8, NOTE_B4,8, NOTE_CS5,8, NOTE_D5,8, NOTE_B4,8, NOTE_D5,8, NOTE_E5,8, REST,8,
REST,8, NOTE_CS5,8, NOTE_B4,8, NOTE_A4,-4, REST,4,
REST,8, NOTE_B4,8, NOTE_B4,8, NOTE_CS5,8, NOTE_D5,8, NOTE_B4,8, NOTE_A4,4, NOTE_E5,8, NOTE_E5,8, NOTE_E5,8, NOTE_FS5,8, NOTE_E5,4, REST,4,

};

int hard_tempo = 80;
int tempo = 200; // for both mario and game over int credit_tempo = 114;

int wholenote_mario = (60000 * 4) / tempo;
int wholenote_hard = (60000 * 4) / hard_tempo;
int wholenote_credit = (60000 * 4) / credit_tempo;
int wholenote_gameover = (60000 * 4) / tempo;
int notes = sizeof(melody) / sizeof(melody[0]) / 2; // for mario int notes_hard = sizeof(hardMelody) / sizeof(hardMelody[0]) / 2; int notes_gameover = sizeof(gameOver) / sizeof(gameOver[0]) / 2; int notes_credit = sizeof(creditMelody) / sizeof(hardMelody[0]) / 2;

const int easyAddress = 0;
const int medAddress = 2; // Assuming sizeof(int) == 2 on target const int highAddress = 4;
const int INIT_MARKER_ADDR = 6;
const float HOMING_FACTOR = 0.8;

// --- Global Variables () ---
bool beat_easy = 0; // Used in original handleGameOver - ref v5 bool beat_med = 0; // Used in original handleGameOver - ref v5
bool beat_hard = 0; // Used in original handleGameOver - ref v5

Adafruit_ILI9341 tft(TFT_CS, TFT_DC, TFT_RST); // this declr initalizes the tft display -
//basically, the white startup and a then flashdown animation that happens at the start is due to this

// --- Moving Platform Constants () ---
const int PLATFORM_MOVE_SPEED = 1;
const int PLATFORM_MOVE_RANGE = 50; // movement range

// <<< NEW: Flags for menu drawing state >>>
static bool mainMenuFirstDraw = true;
static bool levelMenuFirstDraw = true; static bool highScoresDrawn = false; static bool creditsDrawn = false; static bool gameOverMsgDrawn = false;

// === EEPROM Function (Original ) ===
void initializeEEPROM() {
//Serial.println("Initializing EEPROM check...");
if (EEPROM.read(INIT_MARKER_ADDR) != 0x33) { // Check new marker address //Serial.println("Initializing EEPROM with default high score values"); EEPROM.put(easyAddress, highScore.easy_score);
EEPROM.put(medAddress, highScore.med_score);
EEPROM.put(highAddress, highScore.hard_score); EEPROM.write(INIT_MARKER_ADDR, 0x33); // Write marker to new address } else {
//Serial.println("EEPROM already initialized."); EEPROM.get(easyAddress, highScore.easy_score);
//Serial.print("Easy Level High Score = "); Serial.println(highScore.easy_score);
EEPROM.get(medAddress, highScore.med_score);
//Serial.print("Med Level High Score = "); Serial.println(highScore.med_score); EEPROM.get(highAddress, highScore.hard_score);
//Serial.print("Hard Level High Score = "); Serial.println(highScore.hard_score);
}
}

// === Setup Function (MODIFIED for State Machine) ===
void setup() {
//Serial.begin(115200);
//Serial.println("v5 Base Code + New Menu Setup..."); // Identify version

// Hardware Init ()
pinMode(TFT_RST, OUTPUT);
pinMode(JOY_SW, INPUT_PULLUP);
digitalWrite(TFT_RST, LOW); delay(10); digitalWrite(TFT_RST, HIGH); delay(10);

tft.begin();
tft.setRotation(0);
SPI.setClockDivider(SPI_CLOCK_DIV2); // Keep as per code

// EEPROM Init ()
initializeEEPROM();
// EEPROM gets (redundant if initializeEEPROM does it, but keep if intended) EEPROM.get(easyAddress, highScore.easy_score);
EEPROM.get(medAddress, highScore.med_score);
EEPROM.get(highAddress, highScore.hard_score);

// <<< NEW: Initialize state machine >>> state.currentMenu = MAIN_MENU; // Start at main menu state.mainMenuSelection = 0;

state.gameOver = true; // Ensure game isn't running initially state.levelSelected = false; // Reset flag

randomSeed(analogRead(A0)); // Seed random generator (use a floating pin like A0) }

// === Main Loop (REPLACED with State Machine) ===
void loop() {
updateMusic();
switch (state.currentMenu) {
case MAIN_MENU:
drawMainMenu();
readMenuInput(); // New non-blocking input handler break;
case LEVEL_MENU:
drawLevelMenu(); // New non-blocking draw handler readMenuInput(); // New non-blocking input handler break;
case HIGHSCORES_MENU:
drawHighScores();
readMenuInput();
break;
case CREDITS_MENU:
drawCredits();
readMenuInput();
break;
case GAME_PLAYING:
// Use original game loop structure if (!state.gameOver) {
// Original throttle logic
static uint32_t lastUpdate = 0;
if (millis() - lastUpdate < 33) return; // Original throttle lastUpdate = millis();

updateGame(); // Calls ORIGINAL updateGame
drawGame(); // Calls ORIGINAL drawGame
} else {
// If gameOver becomes true, transition state
// updateHighScore logic moved into handleGameOver state.currentMenu = GAME_OVER_STATE; resetDrawFlags();
}
break;
case GAME_OVER_STATE:
handleGameOver(); | // Display score, update EEPROM (Adapted from
original)
readMenuInput_GameOver(); // Wait for input to return to menu
break;
}
}

// === NEW Menu Drawing Functions ===
void resetDrawFlags() {
mainMenuFirstDraw = true; levelMenuFirstDraw = true;
highScoresDrawn = false; creditsDrawn = false; gameOverMsgDrawn = false; }

void drawMainMenu() {
static int lastSelection = -1;
if (state.mainMenuSelection != lastSelection || mainMenuFirstDraw) { if (mainMenuFirstDraw) {

tft.fillScreen(BLACK); tft.setTextColor(WHITE); tft.setTextSize(4); tft.setCursor(10, 30); tft.print("DOODLUINO"); tft.setTextSize(2); mainMenuFirstDraw = false;
} else { tft.fillRect(35, 110, 170, 130, BLACK); }

const char* menuItems[] = {"LEVEL SELECT", "HIGH SCORES", "CREDITS"}; for (int i = 0; i < 3; i++) {
int yPos = 120 + (i * 40);
uint16_t fgColor = WHITE, bgColor = GREEN;
if (i == state.mainMenuSelection) { tft.fillRoundRect(40, yPos - 5, 160, 30, 5, bgColor); fgColor = BLACK; }
tft.setTextColor(fgColor);
int textWidth = strlen(menuItems[i]) * 6 * 2;
tft.setCursor(SCREEN_WIDTH / 2 - textWidth / 2, yPos); tft.print(menuItems[i]);
}
lastSelection = state.mainMenuSelection;
}
tft.fillRect(-3,150,PLATFORM_WIDTH-8, PLATFORM_HEIGHT, GREEN); tft.fillRect(190,100,PLATFORM_WIDTH-5, PLATFORM_HEIGHT, GREEN); tft.fillRect(100,250,PLATFORM_WIDTH-5, PLATFORM_HEIGHT, GREEN); // dont - oh no!!!
tft.fillRect(4,290,PLATFORM_WIDTH-5, PLATFORM_HEIGHT, GREEN); tft.fillRect(150,340,PLATFORM_WIDTH-5, PLATFORM_HEIGHT, GREEN); tft.fillRect(210,220,PLATFORM_WIDTH-5, PLATFORM_HEIGHT, GREEN); tft.fillRect(17, 260 ,DOODLER_WIDTH, DOODLER_HEIGHT, WHITE);

tft.setCursor(180,300);
tft.print("V7.0");
}

void drawLevelMenu() {
static int lastSelection = -1;
const int numOptions = 4; // Easy, Med, Hard, Back
if (state.selectedOption != lastSelection || levelMenuFirstDraw) {
if (levelMenuFirstDraw) {
tft.fillScreen(BLACK); tft.setTextColor(WHITE); tft.setTextSize(3); tft.setCursor(30, 30); tft.print("SELECT LEVEL"); tft.setTextSize(2); levelMenuFirstDraw = false;
} else { tft.fillRect(35, 110, 170, 170, BLACK); } // Clear menu area + back

for (int i = 0; i < numOptions; i++) { // Loop includes Back option
int yPos = 120 + (i * 40);
bool isSelected = (i == state.selectedOption);
uint16_t color = BLUE; // Default highlight for Back
uint16_t textColor = WHITE;
const char* optionText = "";

if (isSelected) {
if (i == LEVEL_EASY) color = GREEN; else if (i == LEVEL_MEDIUM) color = YELLOW; else if (i == LEVEL_HARD) color = RED; tft.fillRoundRect(40, yPos - 5, 160, 30, 5, color);
}

switch (i) {
case LEVEL_EASY: optionText = "EASY"; textColor = (isSelected ? BLACK : WHITE); break;
case LEVEL_MEDIUM: optionText = "MEDIUM"; textColor = (isSelected ? BLACK : BLUE); break;

case LEVEL_HARD: optionText = "HARD"; textColor = (isSelected ? BLACK : WHITE); break;
case 3: optionText = "BACK"; textColor = (isSelected ? WHITE : RED); break; }
tft.setTextColor(textColor);
int textWidth = strlen(optionText) * 6 * 2;
tft.setCursor(SCREEN_WIDTH / 2 - textWidth / 2, yPos); tft.print(optionText); }
lastSelection = state.selectedOption;
}
}

void drawHighScores() {
if (!highScoresDrawn) {
tft.fillScreen(BLACK); tft.setTextColor(WHITE); tft.setTextSize(2); tft.setCursor(20, 30); tft.print("HIGH SCORES");
tft.setCursor(60, 80); tft.print("EASY: "); tft.print(highScore.easy_score); tft.setCursor(60, 120); tft.print("MEDIUM: "); tft.print(highScore.med_score);
tft.setCursor(60, 160); tft.print("HARD: "); tft.print(highScore.hard_score); tft.setTextColor(RED); tft.setCursor(20, 220); tft.print("Press Select to BACK");
highScoresDrawn = true;
}
}

void drawCredits() {
if (!creditsDrawn) {
tft.fillScreen(BLACK); tft.setTextColor(WHITE); tft.setTextSize(3); tft.setCursor(60, 50); tft.print("CREDITS"); tft.setTextSize(2); tft.setCursor(30, 120); tft.print("Game By: LUKOG"); // name

tft.setTextColor(RED); tft.setCursor(20, 220); tft.print("Press Select to BACK");
creditsDrawn = true;
}
}

// === NEW Input Handling Functions ===
void readMenuInput() {
static uint32_t lastInputTime = 0; uint32_t now = millis(); if (now -lastInputTime < 180) return;
int yValue = analogRead(JOY_Y); int swValue = digitalRead(JOY_SW); bool inputProcessed = false; int currentSelection = 0; int maxOption = 0;

switch(state.currentMenu) {
case MAIN_MENU: currentSelection = state.mainMenuSelection; maxOption = 2; break;
case LEVEL_MENU: currentSelection = state.selectedOption; maxOption = 3; break;
case HIGHSCORES_MENU: case CREDITS_MENU: break; default: return;
}
if (state.currentMenu == MAIN_MENU || state.currentMenu == LEVEL_MENU) {
// Use thresholds consistent with original readMenuInput if different
if (yValue > 600) { currentSelection++; if (currentSelection > maxOption) currentSelection = 0; inputProcessed = true; }
else if (yValue < 400) { currentSelection--; if (currentSelection < 0) currentSelection = maxOption; inputProcessed = true; }
if (inputProcessed) { if(state.currentMenu == MAIN_MENU) state.mainMenuSelection = currentSelection; else if (state.currentMenu == LEVEL_MENU) state.selectedOption = currentSelection; lastInputTime = now; } }

if (swValue == LOW) { handleMenuSelection(); lastInputTime = now + 250; } // Debounce after select
}

void handleMenuSelection() {
int previousMenu = state.currentMenu; switch(state.currentMenu) {
case MAIN_MENU:
switch(state.mainMenuSelection) {
case 0: state.currentMenu = LEVEL_MENU; state.selectedOption = 0; break;
case 1: state.currentMenu = HIGHSCORES_MENU; break;
case 2: state.currentMenu = CREDITS_MENU;
state.currentMenu = CREDITS_MENU; state.musicState = MUSIC_CREDITS; state.currentMelody = creditMelody; state.currentTempo = credit_tempo; state.currentNotesCount =
sizeof(creditMelody)/sizeof(creditMelody[0])/2; state.currentMelodyNote = 0; break;
} break;
case LEVEL_MENU:
if (state.selectedOption == 3) { state.currentMenu = MAIN_MENU; state.mainMenuSelection = 0; }
else { state.gameLevel = state.selectedOption; state.levelSelected = true; state.currentMenu = GAME_PLAYING; tft.fillScreen(RED); delay(2);
tft.fillScreen(YELLOW);
delay(2);
tft.fillScreen(GREEN);
delay(2);
tft.fillScreen(BLACK);initGame(); } // Calls ORIGINAL initGame break;
case HIGHSCORES_MENU: case CREDITS_MENU: state.currentMenu = MAIN_MENU; state.musicState = MUSIC_OFF; noTone(BUZZER_PIN); state.mainMenuSelection = (previousMenu == HIGHSCORES_MENU) ? 1 : 2; break;
}
if (state.currentMenu != previousMenu) { resetDrawFlags(); }
}

void readMenuInput_GameOver() {
static uint32_t lastInputTime_GO = 0; uint32_t now = millis(); if (now -lastInputTime_GO < 400) return;
if (digitalRead(JOY_SW) == LOW) { state.currentMenu = MAIN_MENU; state.mainMenuSelection = 0; state.gameOver = true; lastInputTime_GO = now; resetDrawFlags(); }
}

void updateGame() { // Modify existing updateGame

// Store previous positions first state.prevDoodlerX = state.doodlerX; state.prevDoodlerY = state.doodlerY;

// <<< NEW: Check if the game is active >>> if (!state.gameIsActive) {
// --- PRE-GAME IDLE STATE ---

// 1. Check for Start Trigger (Joystick Button Press)

if (digitalRead(JOY_SW) == LOW) {
state.gameIsActive = true; // Start the game! state.doodlerVelocityY = JUMP_FORCE; // Apply initial full jump force // Serial.println("Game Started!"); // Debug message

return; // Skip rest of update for this frame
}

// 2. Idle Bounce Physics (simple bounce on platform 0)
const float IDLE_GRAVITY = 0.1f; // Very weak gravity for idle const float IDLE_JUMP = -1.5f; // Small upward bounce velocity

state.doodlerVelocityY += IDLE_GRAVITY; // Apply weak gravity state.doodlerY += state.doodlerVelocityY; // Update position

// Collision check ONLY with platform 0 (the starting one)
int i = 0; // Index of the starting platform
bool xOverlap = (state.doodlerX + DOODLER_WIDTH > state.platformX[i]) && (state.doodlerX < state.platformX[i] + PLATFORM_WIDTH); // Simplified Y check for idle bounce (are feet at or below platform top?) bool yLanded = (state.doodlerY + DOODLER_HEIGHT >= state.platformY[i]);

// Apply bounce only if falling and landed
if (xOverlap && yLanded && state.doodlerVelocityY >= 0) { state.doodlerVelocityY = IDLE_JUMP; // Apply small bounce state.doodlerY = state.platformY[i] - DOODLER_HEIGHT; // Snap to top }

// Make sure regular platforms update their prev positions but don't move // Call original updatePlatforms but it should ideally do nothing if level==easy
// or if platformDirection is 0 for the relevant platforms
updatePlatforms(); // Keep original call - needed to update prevX/Y for drawing

} else {
// --- ACTIVE GAME STATE

// Input handling (Horizontal)
int joy = analogRead(JOY_X);
// Use the horizontal control logic from v5 code:
state.doodlerX += (joy < 400) ? +5 : (joy > 600) ? -5 : 0; // Assuming this is v5 logic
// Screen wrap
if (state.doodlerX < 0) state.doodlerX = SCREEN_WIDTH - DOODLER_WIDTH;
if (state.doodlerX > SCREEN_WIDTH - DOODLER_WIDTH) state.doodlerX = 0;

// Physics (Normal Gravity - using original dynamic gravity)
float dynamicGravity = BASE_GRAVITY + (state.score * GRAVITY_INCREASE); state.displayGravity = dynamicGravity;
state.doodlerVelocityY += dynamicGravity;
// Apply terminal velocity (optional)
// state.doodlerVelocityY = min(state.doodlerVelocityY, 15.0f); state.doodlerY += state.doodlerVelocityY;

// Standard Game Logic Calls ( Original Functions) updateObstacles();
checkCollisions();
handleScrolling();
updatePlatforms(); // Platforms will move now based on level/direction checkGameOver();
}

}

void updatePlatforms() {
int moveSpeed = PLATFORM_MOVE_SPEED;

// Adjust speed based on level and score if (state.gameLevel == LEVEL_HARD) { moveSpeed += state.score * 0.25;
}

for (int i = 0; i < NUM_PLATFORMS; i++) {
if (state.gameLevel != LEVEL_EASY) {
state.platformX[i] += moveSpeed * state.platformDirection[i]; // Boundary check
if (state.platformX[i] <= 0) {
state.platformDirection[i] = 1;
state.platformX[i] = 0;
} else if (state.platformX[i] >= SCREEN_WIDTH - PLATFORM_WIDTH) { state.platformDirection[i] = -1;
state.platformX[i] = SCREEN_WIDTH - PLATFORM_WIDTH;
}
}
}
}

void updateObstacles() {
// Calculate current max obstacles based on score (1 + 1 per 10 points) int currentMaxObstacles = 1 + (state.score / 10);
currentMaxObstacles = min(currentMaxObstacles, MAX_OBSTACLES);

// Spawn new obstacles
if (state.score >= OBSTACLE_START_SCORE && random(100) < OBSTACLE_SPAWN_CHANCE) { for (int i = 0; i < currentMaxObstacles; i++) { // Only check allowed slots if (!state.obstacleActive[i]) {
state.obstacleActive[i] = true;
state.obstacleX[i] = random(OBSTACLE_RADIUS, SCREEN_WIDTH -OBSTACLE_RADIUS);

// Homing effect only in Hard mode
if (state.gameLevel == LEVEL_HARD) {
float horizontalDifference = state.doodlerX - state.obstacleX[i]; if (horizontalDifference > 5) {
state.obstacleX[i] += HOMING_FACTOR;
}
else if (horizontalDifference < -5) { state.obstacleX[i] -= HOMING_FACTOR;
}
// Keep within bounds after adjustment state.obstacleX[i] = constrain(state.obstacleX[i], OBSTACLE_RADIUS,
SCREEN_WIDTH - OBSTACLE_RADIUS);
}

state.obstacleY[i] = random(-PLATFORM_HEIGHT+20, 0); state.obstacleDir[i] = (random(2) ? 1 : -1); state.prevObstacleX[i] = state.obstacleX[i]; state.prevObstacleY[i] = state.obstacleY[i];
break;
}
}

}

// Move active obstacles - only in Hard mode for (int i = 0; i < MAX_OBSTACLES; i++) {
if (state.obstacleActive[i]) { state.prevObstacleX[i] = state.obstacleX[i]; state.prevObstacleY[i] = state.obstacleY[i];

// Only move obstacles in Hard difficulty
if (state.gameLevel == LEVEL_HARD) {
state.obstacleX[i] += OBSTACLE_SPEED * state.obstacleDir[i];

// Bounce logic
if (state.obstacleX[i] <= OBSTACLE_RADIUS || state.obstacleX[i] >= SCREEN_WIDTH - OBSTACLE_RADIUS) { state.obstacleDir[i] *= -1;
// Prevent sticking at edges
state.obstacleX[i] = constrain(state.obstacleX[i], OBSTACLE_RADIUS,
SCREEN_WIDTH - OBSTACLE_RADIUS);
}
}
}
}
}
void drawGame() {
static int lastScore = -1;
if (state.score != lastScore) {
if (state.score <= 10) {
tft.fillRect(0, 0, SCREEN_WIDTH, TOP_OFFSET - 10, RED); } else if (state.score > 10 && state.score <= 30) { tft.fillRect(0, 0, SCREEN_WIDTH, TOP_OFFSET - 10, BLUE); } else if (state.score > 30 && state.score < 50) { tft.fillRect(0, 0, SCREEN_WIDTH, TOP_OFFSET - 10, CYAN); } else if (state.score >= 50 && state.score <= 89) { tft.fillRect(0, 0, SCREEN_WIDTH, TOP_OFFSET - 10, GREEN); }
tft.setCursor(5, 5);
tft.setTextColor(WHITE);
tft.print("Score: ");

tft.print(state.score);
lastScore = state.score;
// tft.setf
tft.setCursor(150,5);
tft.print("g: ");
tft.print(state.displayGravity);

}

// Clear previous doodler position tft.fillRect(state.prevDoodlerX, state.prevDoodlerY + TOP_OFFSET, DOODLER_WIDTH, DOODLER_HEIGHT, BLACK); // Draw new doodler position
tft.fillRect(state.doodlerX, state.doodlerY + TOP_OFFSET, DOODLER_WIDTH, DOODLER_HEIGHT, WHITE);

// Update platforms
int visiblePlatforms = NUM_PLATFORMS; // Default to NUM_PLATFORMS

if (state.gameLevel != LEVEL_EASY) {
if (state.score > 10 && state.score < 20) {

// Reduce visible platforms gradually
visiblePlatforms = NUM_PLATFORMS - (int)((state.score - 10) * 0.3); // Reduce by 3 between 10-20
visiblePlatforms = max(4, visiblePlatforms); // Ensure at least 4 are visible }
}

for (int i = 0; i < NUM_PLATFORMS; i++) {
if (i < visiblePlatforms && // Only draw visible platforms state.platformY[i] + TOP_OFFSET >= 0 && state.platformY[i] + TOP_OFFSET < SCREEN_HEIGHT) {
if (state.platformX[i] != state.prevPlatformX[i] ||
state.platformY[i] != state.prevPlatformY[i]) { tft.fillRect(state.prevPlatformX[i], state.prevPlatformY[i] + TOP_OFFSET, PLATFORM_WIDTH, PLATFORM_HEIGHT, BLACK); }

tft.fillRect(state.platformX[i], state.platformY[i] + TOP_OFFSET, PLATFORM_WIDTH, PLATFORM_HEIGHT, GREEN); state.prevPlatformX[i] = state.platformX[i]; state.prevPlatformY[i] = state.platformY[i];
}
}
if (!state.gameIsActive) { tft.setTextColor(YELLOW);
tft.setTextSize(2);
const char* startText = "Press Start!";
int16_t x1, y1;
uint16_t w, h;
tft.getTextBounds(startText, 0, 0, &x1, &y1, &w, &h); // Get text bounds // Position near bottom center
tft.setCursor(SCREEN_WIDTH / 2 - w / 2, SCREEN_HEIGHT - h - 10); tft.print(startText);
}

// <<< NEW: Draw obstacles >>>
for (int i = 0; i < MAX_OBSTACLES; i++) { if (state.obstacleActive[i]) {
// Clear old position
tft.fillCircle(state.prevObstacleX[i], state.prevObstacleY[i] + TOP_OFFSET, OBSTACLE_RADIUS, BLACK);

// Draw new position
tft.fillCircle(state.obstacleX[i], state.obstacleY[i] + TOP_OFFSET, OBSTACLE_RADIUS, OBSTACLE_COLOR); }
}
}

void checkCollisions() {
for (int i = 0; i < NUM_PLATFORMS; i++) {
if (state.platformY[i] + TOP_OFFSET >= 0 && state.platformY[i] + TOP_OFFSET < SCREEN_HEIGHT) { // Visibility check
// Collision check logic
if (state.doodlerVelocityY > 0 &&
state.doodlerX + DOODLER_WIDTH > state.platformX[i] && state.doodlerX < state.platformX[i] + PLATFORM_WIDTH && state.prevDoodlerY + DOODLER_HEIGHT <= state.platformY[i] && state.doodlerY + DOODLER_HEIGHT >= state.platformY[i]) {

// Dynamic jump force (as per original code)
float dynamicJump = JUMP_FORCE - (state.score * 0.1); state.doodlerVelocityY = dynamicJump;
state.doodlerY = state.platformY[i] - DOODLER_HEIGHT; // Snap to top

if (!state.platformUsed[i]) { state.score++; state.platformUsed[i] = true; }
// return; // Original code didn't have return, check implications
}
}
}

// <<< NEW: Obstacle collisions >>>
for (int i = 0; i < MAX_OBSTACLES; i++) {
if (state.obstacleActive[i]) {
// Simple Axis-Aligned Bounding Box (AABB) check for Rect-Circle // More robust and common than the previous distance check.

// Find closest point on doodler rectangle to circle center
float closestX = max((float)state.doodlerX, min((float)state.obstacleX[i], (float)(state.doodlerX + DOODLER_WIDTH)));
float closestY = max((float)state.doodlerY, min((float)state.obstacleY[i], (float)(state.doodlerY + DOODLER_HEIGHT)));

// Calculate distance squared between circle center and closest point float dx = state.obstacleX[i] - closestX;
float dy = state.obstacleY[i] - closestY;
float distanceSquared = (dx * dx) + (dy * dy);

// If distance is less than radius squared, collision!
if (distanceSquared < (OBSTACLE_RADIUS * OBSTACLE_RADIUS)) { state.gameOver = true;
// You might want a sound effect here
// tone(BUZZER_PIN, NOTE_C4, 100); // Example collision sound return; // Exit collision check early
}
}
}

}

// ========== INITIALIZATION ========== // void initGame() {
state.score = 0;
state.gameOver = false;
state.gameIsActive = false; // <<< Game doesn't start immediately state.levelSelected = true; // Mark level as selected if needed

// --- Platform Initialization (Keep original logic) ---state.plat_start_used = false; // From original v5 initGame state.platformX_start = state.doodlerX; // From original v5 initGame state.platformY_start = state.doodlerY - PLAY_AREA_HEIGHT / 2 + 5; // From original v5 initGame
state.visiblePlatforms = VISIBLE_PLATFORMS; // From original v5 initGame

if (state.gameLevel == LEVEL_HARD) {
state.musicState = MUSIC_HARD;
state.currentMelody = hardMelody;
state.currentTempo = hard_tempo;
state.currentNotesCount = sizeof(hardMelody)/sizeof(hardMelody[0])/2; } else {
state.musicState = MUSIC_MAIN;

state.currentMelody = melody;
state.currentTempo = tempo;
state.currentNotesCount = sizeof(melody)/sizeof(melody[0])/2; }
state.currentMelodyNote = 0;
state.previousNoteTime = 0;
state.melodyNoteDuration = 0;

for (int i = 0; i < NUM_PLATFORMS; i++) { state.plat_start_used = true; // From original v5 initGame state.platformUsed[i] = false;
state.platformX[i] = random(SCREEN_WIDTH - PLATFORM_WIDTH); state.platformY[i] = PLAY_AREA_HEIGHT - (i * (PLAY_AREA_HEIGHT / NUM_PLATFORMS));
if (state.gameLevel == LEVEL_EASY) { state.platformDirection[i] = 0; } else { state.platformDirection[i] = (random(2) == 0) ? 1 : -1; } state.prevPlatformX[i] = state.platformX[i];
state.prevPlatformY[i] = state.platformY[i];
}
// --- END Platform Initialization ---

// <<< NEW: Place Doodler ON the starting platform (platform[0]) >>>
// Ensure platform 0 is positioned reasonably for start
state.platformX[0] = SCREEN_WIDTH / 2 - PLATFORM_WIDTH / 2; // Center first platform
state.platformY[0] = PLAY_AREA_HEIGHT - 60; // Place it relatively low state.prevPlatformX[0] = state.platformX[0]; // Update its prev position too state.prevPlatformY[0] = state.platformY[0];

// Set doodler position based on platform 0
state.doodlerX = state.platformX[0] + (PLATFORM_WIDTH / 2) - (DOODLER_WIDTH / 2); state.doodlerY = state.platformY[0] - DOODLER_HEIGHT; // Place doodler feet on platform 0

state.doodlerVelocityY = -1.5; // <<< Small initial upward velocity for idle bounce

state.prevDoodlerX = state.doodlerX;
state.prevDoodlerY = state.doodlerY;

resetDrawFlags();

// Initialize obstacles

for (int i = 0; i < MAX_OBSTACLES; i++) { state.obstacleActive[i] = false;
state.obstacleX[i] = -100; // Off-screen
state.obstacleY[i] = -100;
state.obstacleDir[i] = (random(2) ? 1 : -1); // Random initial direction }
}

void updateMusic() {
if (state.musicState == MUSIC_OFF) return;

unsigned long currentTime = millis();
// Check if it's time for the next note based on the *previous* note's duration if (currentTime - state.previousNoteTime >= state.melodyNoteDuration) {

// Check if we are still within the melody bounds
if (state.currentMelodyNote < state.currentNotesCount * 2) {

// --- CORRECT: Access PROGMEM data using pgm_read_word_near() ---
// Read the note frequency from PROGMEM
int note = pgm_read_word_near(state.currentMelody + state.currentMelodyNote); // Read the note duration specifier from PROGMEM
int duration = pgm_read_word_near(state.currentMelody + state.currentMelodyNote + 1);
// ---------------------------------------------------------------

// Calculate the duration for THIS note (will be used for the NEXT check) int wholenote = (60000 * 4) / state.currentTempo;
int divider = duration;
if (divider > 0) {
state.melodyNoteDuration = wholenote / divider;
} else {
// Handle dotted notes (negative divider) state.melodyNoteDuration = (wholenote / abs(divider)) * 1.5; }

// Play the note (if it's not a rest)
if (note == REST) {
noTone(BUZZER_PIN);
} else {
// Play note for 90% of its calculated duration tone(BUZZER_PIN, note, state.melodyNoteDuration * 0.9); }

// Update the time the last note *started* playing state.previousNoteTime = currentTime;

// Increment index AFTER reading and calculating duration for the current note pair
state.currentMelodyNote += 2;

} else {
// Reached the end of the melody switch(state.musicState) { case MUSIC_MAIN:
case MUSIC_HARD:
case MUSIC_CREDITS:
state.currentMelodyNote = 0; // Loop back to the beginning
// Optionally reset previousNoteTime and melodyNoteDuration to avoid initial delay?
// state.previousNoteTime = currentTime; // Start next loop check immediately
// state.melodyNoteDuration = 0; // Ensure first note plays right away break;
case MUSIC_GAME_OVER:
state.musicState = MUSIC_OFF; // Play only once
noTone(BUZZER_PIN);
break;
}
}
}
}

void handleGameOver() {
// Update High Score (using exact logic from original handleGameOver)

state.musicState = MUSIC_OFF;

noTone(BUZZER_PIN);;

state.musicState = MUSIC_GAME_OVER;
state.currentMelody = gameOver;
state.currentTempo = tempo;
state.currentNotesCount = sizeof(gameOver)/sizeof(gameOver[0])/2; state.currentMelodyNote = 0;

bool highScoreUpdated = false;
// Reset local flags each time entering this state beat_easy = 0; beat_med = 0; beat_hard = 0;

if (state.gameLevel == LEVEL_EASY) {
if (state.score > highScore.easy_score) { highScore.easy_score = state.score; beat_easy = 1; highScoreUpdated = true; } } else if (state.gameLevel == LEVEL_MEDIUM) {
if (state.score > highScore.med_score) { highScore.med_score = state.score; beat_med = 1; highScoreUpdated = true; }
} else if (state.gameLevel == LEVEL_HARD) {
if (state.score > highScore.hard_score) { highScore.hard_score = state.score; beat_hard = 1; highScoreUpdated = true; } }

// EEPROM update
if (highScoreUpdated) {
int addressToUpdate = 0; int scoreToSave = 0;
if (state.gameLevel == LEVEL_EASY) { addressToUpdate = easyAddress; scoreToSave = highScore.easy_score; } else if (state.gameLevel == LEVEL_MEDIUM) { addressToUpdate = medAddress; scoreToSave = highScore.med_score; } else { addressToUpdate = highAddress; scoreToSave = highScore.hard_score; } EEPROM.update(addressToUpdate, lowByte(scoreToSave)); EEPROM.update(addressToUpdate + 1, highByte(scoreToSave));
// Verification (as per original code)
int readBackValue; EEPROM.get(addressToUpdate, readBackValue); // Use get for verification
if (readBackValue != scoreToSave) { //Serial.print("EEPROM Write Error! Addr: "); /* ... */ }
else { //Serial.println("EEPROM Save Verified."); }
}

// Draw Game Over Screen (only once per entry using global flag) if (!gameOverMsgDrawn) {
tft.fillScreen(BLACK);
tft.setTextSize(2);
tft.setCursor(50, 50); tft.setTextColor(RED); tft.print("GAME OVER :("); // Original text
tft.setCursor(50, 100); tft.setTextColor(WHITE); tft.print("You scored: "); tft.print(state.score);
if (highScoreUpdated) { tft.setTextColor(YELLOW); tft.setCursor(40, 130); tft.print("New High Score!"); } // Optional msg tft.setTextColor(WHITE); tft.setCursor(40, 150); tft.print("Click joystick "); tft.setCursor(60, 180); tft.print("to restart"); // Original text gameOverMsgDrawn = true;
}
}

void checkGameOver() { // Original if (state.doodlerY > SCREEN_HEIGHT) state.gameOver = true;
}

void handleScrolling() {
float dynamicScroll = BASE_SCROLL + (state.score * SCROLL_INCREASE);
if (state.doodlerY < PLAY_AREA_HEIGHT / 3) {
int scroll = min(PLAY_AREA_HEIGHT / 3 - state.doodlerY, (int)dynamicScroll); state.doodlerY += scroll;

// Scroll platforms
for (int i = 0; i < NUM_PLATFORMS; i++) { state.platformY[i] += scroll;

// Regenerate platforms that scroll off bottom
if (state.platformY[i] > PLAY_AREA_HEIGHT) {
state.platformX[i] = random(SCREEN_WIDTH - PLATFORM_WIDTH); state.platformY[i] = random(-PLATFORM_HEIGHT, 0); // Spawn above screen state.platformUsed[i] = false;
if (state.gameLevel != LEVEL_EASY) {
state.platformDirection[i] = (random(2) ? 1 : -1);
}
}
}

// Scroll obstacles
for (int i = 0; i < MAX_OBSTACLES; i++) { if (state.obstacleActive[i]) { state.obstacleY[i] += scroll;

// Remove obstacles that scroll off bottom if (state.obstacleY[i] > PLAY_AREA_HEIGHT) { state.obstacleActive[i] = false;
}
}
}
}
}

# Things That Were Dropped–

# List of features that were included in my project proposal, but have been dropped in the final version due to better alternatives/ hardware limitations/ non-feasibility/ similar reasons –

# 1. A secondary LCD to display real-time position and velocity data - Found it

redundant to have a 2nd screen. I came up with a better alternative to create sections on my 2.8” TFT display, display details such as score and gravity with real-time updates.

# 2. An SD card reader to read and display/ play images and music – It seems that the SPI driver on Uno can drive only one component at time – either work as a MOSI (Master Out Slave In – Arduino acting as the master and the TFT being the slave) or MISO

(Master-in Slave-Out, just the opposite), but not both simultaneously. Since, I had to play the game (MOSI) and play music (MISO), this was simply not possible on an Uno.

# 3. Game Features:

- Shrinking and elongating platforms – felt it to be unnecessary - Black hole as obstacles – too complex and memory demanding, also didn’t go well with SPI framerate – made the game too slow (ref: my GitHub repo, (https://github.com/ramanan849/Doodluino) code V5.5) - Display of real-time position and velocity – again, the same issue of

insufficient SPI rate.

# Bibliography –

## - https://github.com/robsoncouto/arduino-songs - https://docs.arduino.cc/retired/getting-started-guides/TFT/ - https://docs.arduino.cc/libraries/tft_espi/ - https://docs.arduino.cc/learn/programming/eeprom-guide/

# Credits –

# Huge thanks to

# - The Professor, and all the Digital lab staff for their immense help throughout - My friends, who provided me with valuable suggestions for various game features - My Beta Tester (aka, my roommate)

***

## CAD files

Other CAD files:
consoluino v3.f3d
